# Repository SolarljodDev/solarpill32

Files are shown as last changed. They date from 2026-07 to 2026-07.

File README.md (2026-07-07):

# SolarPill32

A small, STM32-pin-compatible development/breakout board built around the
**CH32V303CBT6** (WCH, RISC-V32, LQFP-48). Footprint and pinout follow the
classic "blue pill / black pill" layout used by STM32F103C8T6 boards, so it
can be used as a drop-in RISC-V alternative in existing STM32 blue/black pill
projects and carriers.

## Board

- MCU: CH32V303CBT6, LQFP-48, 7x7 mm, 0.5 mm pitch (custom footprint
  `LQFP-48_7x7mm_P0.5mm.kicad_mod` included, as it's not in stock KiCad
  libraries).
- 4-layer PCB: top/bottom signal layers plus dedicated GND and 3V3 inner
  planes.
- Designed in KiCad 9.

## Repository contents

| Path | Description |
|---|---|
| `ch32_v303cb.kicad_pro/.kicad_sch/.kicad_pcb` | Main board project (schematic, layout) |
| `filter.kicad_sch` | Hierarchical sheet: power supply filtering |
| `LQFP-48_7x7mm_P0.5mm.kicad_mod` | Custom footprint for the CH32V303CBT6 |
| `SW_conv/` | Secondary small PCB project: switching converter module |
| `gerber/` | Exported Gerber + drill files for fabrication |

Files that KiCad regenerates automatically (autosave backups, `.lck` lock
files, `fp-info-cache`, local `.kicad_prl` view-state files, editor history)
are intentionally excluded — see `.gitignore`.

## License

Hardware design files (schematics, PCB layout, footprints, Gerbers) in this
repository are licensed under the
[CERN Open Hardware Licence Version 2 - Strongly Reciprocal (CERN-OHL-S-2.0)](LICENSE).

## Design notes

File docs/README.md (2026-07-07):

# SolarPill32 pinout configurator

Self-contained interactive HTML page: IDC pin layouts for all 5 headers, with
checkboxes to toggle alternate peripheral functions per pin group. Conflicting
selections (two peripherals wanting the same physical pin) are highlighted
live on the ribbon diagram and pin table.

No build step, no dependencies — `index.html` is the whole page (fonts are
inlined as base64). Open it directly in a browser, or serve this folder
(e.g. via GitHub Pages) as-is.

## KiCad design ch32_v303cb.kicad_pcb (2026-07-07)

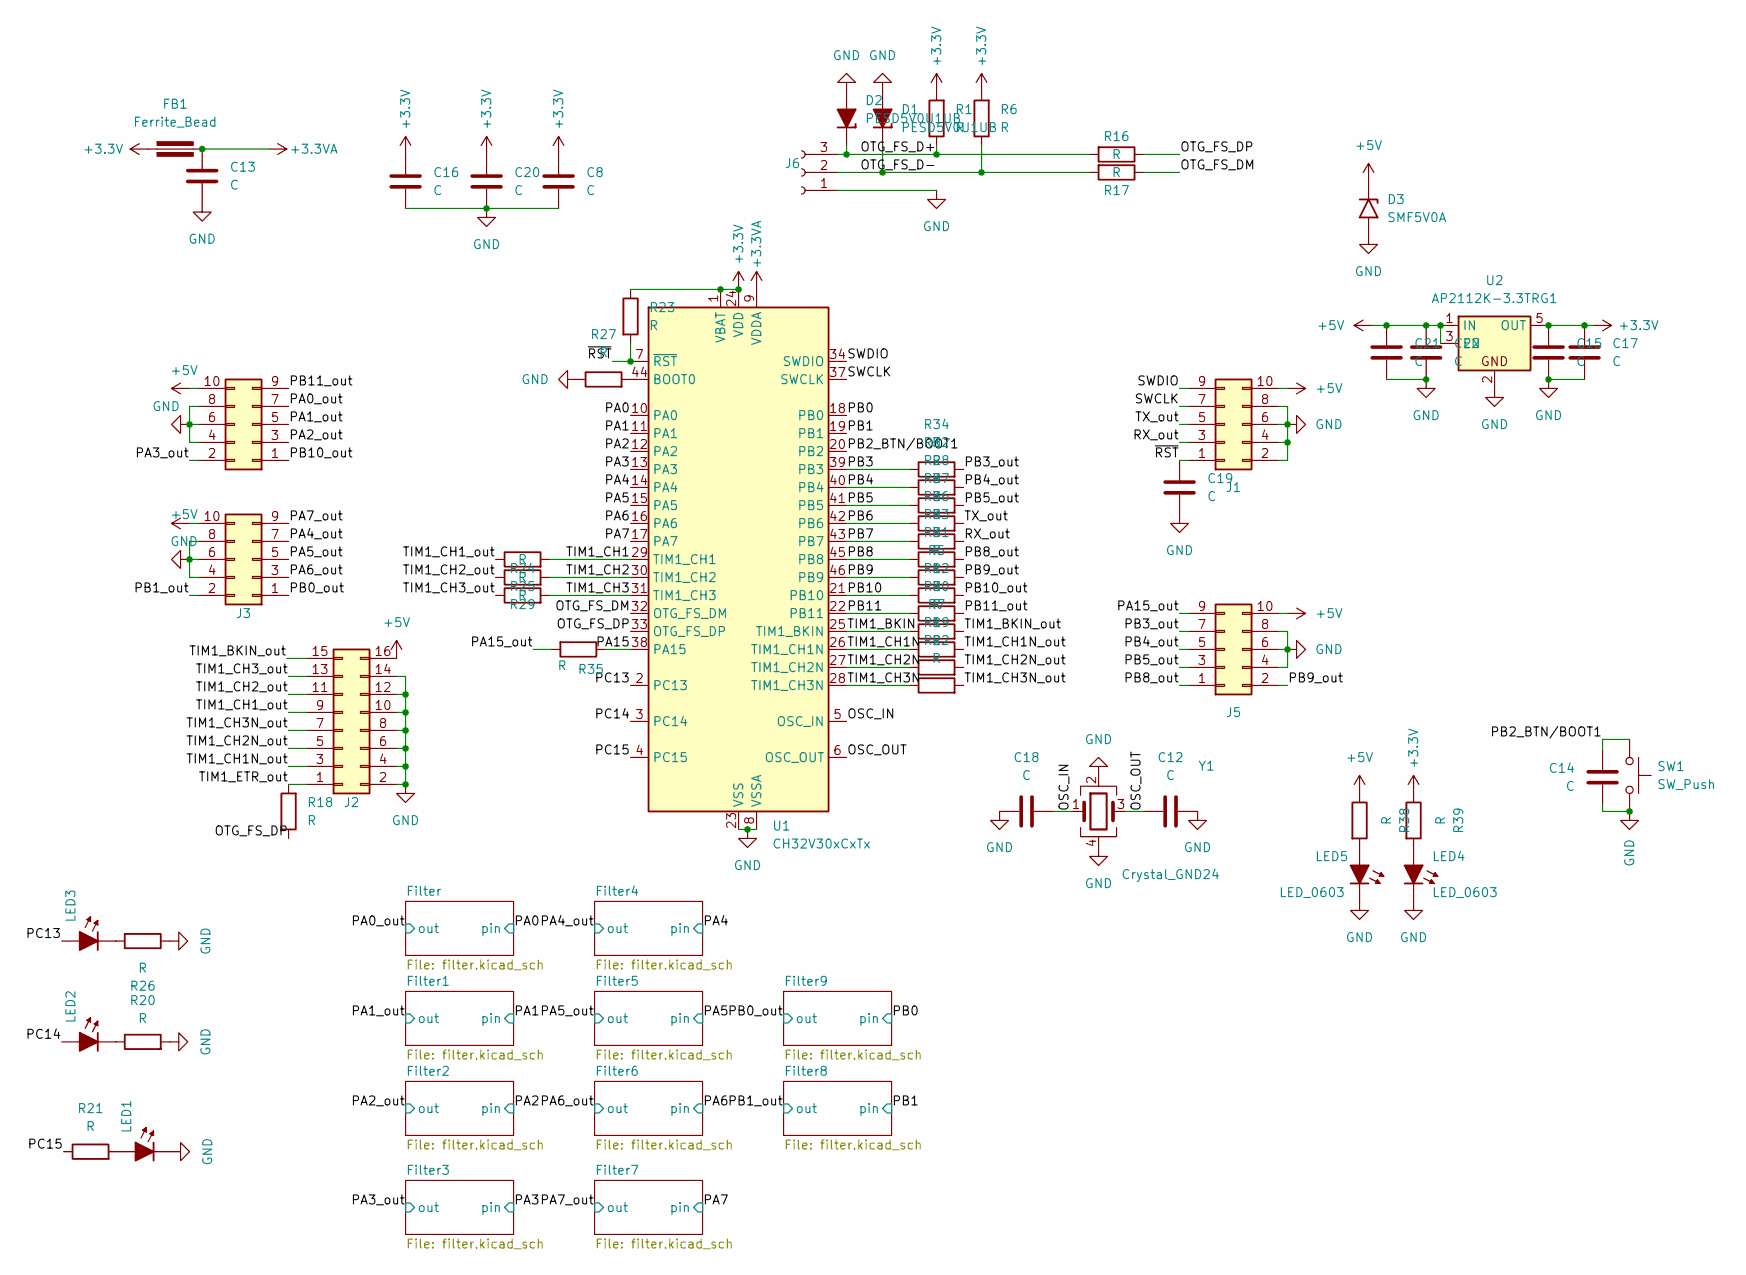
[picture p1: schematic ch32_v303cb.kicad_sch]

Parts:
C8, C12, C13, C14, C15, C16, C17, C18, C19, C20, C21, C22: C; C_0603
D1, D2: PESD5V0U1UB; D_SOD-523
D3: SMF5V0A; D_SMF
FB1: Ferrite_Bead; Ferrite_0603
J1, J3, J4, J5: Conn_02x05_Odd_Even; IDC-Header_2x5_P2.54mm_Horizontal_EDGE
J2: Conn_02x08_Odd_Even; IDC-Header_2x8_P2.54mm_Horizontal_EDGE
J6: Conn_01x02_Socket; PinSocket_1x03_P2.00mm_Vertical
LED1, LED2, LED3, LED4, LED5: LED_0603
R1, R5, R6, R7, R12, R16, R17, R18, R19, R20, R21, R22, R23, R24, R25, R26, R27, R28, R29, R30, R31, R32, R33, R34, R35, R36, R37, R38, R39: R; R_0603
SW1: SW_Push; SW_Push_1P1T_XKB_TS-1187A
U1: CH32V30xCxTx; LQFP-48_7x7mm_P0.5mm
U2: AP2112K-3.3TRG1; SOT-23-5
Y1: Crystal_GND24; Q3225

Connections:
+3.3VA: C13.1, FB1.2, U1.9 (VDDA)
+5V: C21.1, C22.1, D3.1 (A1), J1.10, J2.16, J3.10, J4.10, J5.10, R38.1, U2.1 (IN), U2.3 (EN)
/OSC_IN: C18.2, U1.5 (OSC_IN), Y1.1
/OSC_OUT: C12.1, U1.6 (OSC_OUT), Y1.3
/OTG_FS_D+: D2.1 (K), J6.3, R1.1, R16.2
/OTG_FS_D-: D1.1 (K), J6.2, R6.1, R17.2
/OTG_FS_DM: R17.1, U1.32 (OTG_FS_DM)
/OTG_FS_DP: R16.1, R18.1, U1.33 (OTG_FS_DP)
/PA0: U1.10 (PA0); also elsewhere on the board
/PA0_out: J4.7; also elsewhere on the board
/PA1: U1.11 (PA1); also elsewhere on the board
/PA1_out: J4.5; also elsewhere on the board
/PA2: U1.12 (PA2); also elsewhere on the board
/PA2_out: J4.3; also elsewhere on the board
/PA3: U1.13 (PA3); also elsewhere on the board
/PA3_out: J4.2; also elsewhere on the board
/PA4: U1.14 (PA4); also elsewhere on the board
/PA4_out: J3.7; also elsewhere on the board
/PA5: U1.15 (PA5); also elsewhere on the board
/PA5_out: J3.5; also elsewhere on the board
/PA6: U1.16 (PA6); also elsewhere on the board
/PA6_out: J3.3; also elsewhere on the board
/PA7: U1.17 (PA7); also elsewhere on the board
/PA7_out: J3.9; also elsewhere on the board
/PA15: R35.1, U1.38 (PA15)
/PA15_out: J5.9, R35.2
/PB0_out: J3.1; also elsewhere on the board
/PB1: U1.19 (PB1); also elsewhere on the board
/PB1_out: J3.2; also elsewhere on the board
/PB2_BTN/BOOT1: C14.1, SW1.1, U1.20 (PB2)
/PB3: R34.1, U1.39 (PB3)
/PB3_out: J5.7, R34.2
/PB4: R32.1, U1.40 (PB4)
/PB4_out: J5.5, R32.2
/PB5: R28.1, U1.41 (PB5)
/PB5_out: J5.3, R28.2
/PB6: R37.1, U1.42 (PB6)
/PB7: R36.1, U1.43 (PB7)
/PB8: R33.1, U1.45 (PB8)
/PB8_out: J5.1, R33.2
/PB9: R31.1, U1.46 (PB9)
/PB9_out: J5.2, R31.2
/PB10: R5.1, U1.21 (PB10)
/PB10_out: J4.1, R5.2
/PB11: R12.1, U1.22 (PB11)
/PB11_out: J4.9, R12.2
/PC13: LED3.2 (A), U1.2 (PC13)
/PC14: LED2.2 (A), U1.3 (PC14)
/PC15: R21.1, U1.4 (PC15)
/RX_out: J1.3, R36.2
/SWCLK: J1.7, U1.37 (SWCLK)
/SWDIO: J1.9, U1.34 (SWDIO)
/TIM1_BKIN: R30.1, U1.25 (TIM1_BKIN)
/TIM1_BKIN_out: J2.15, R30.2
/TIM1_CH1: R24.2, U1.29 (TIM1_CH1)
/TIM1_CH1N: R7.1, U1.26 (TIM1_CH1N)
/TIM1_CH1N_out: J2.3, R7.2
/TIM1_CH1_out: J2.9, R24.1
/TIM1_CH2: R25.2, U1.30 (TIM1_CH2)
/TIM1_CH2N: R19.1, U1.27 (TIM1_CH2N)
/TIM1_CH2N_out: J2.5, R19.2
/TIM1_CH2_out: J2.11, R25.1
/TIM1_CH3: R29.2, U1.31 (TIM1_CH3)
/TIM1_CH3N: R22.1, U1.28 (TIM1_CH3N)
/TIM1_CH3N_out: J2.7, R22.2
/TIM1_CH3_out: J2.13, R29.1
/TIM1_ETR_out: J2.1, R18.2
/TX_out: J1.5, R37.2
/~RST: C19.1, J1.1, R23.2, U1.7 (~RST)
GND: C8.2, C12.2, C13.2, C14.2, C15.2, C16.2, C17.2, C18.1, C19.2, C20.2, C21.2, C22.2, D1.2 (A), D2.2 (A), D3.2 (A2), J1.2, J1.4, J1.6, J1.8, J2.2, J2.4, J2.6, J2.8, J2.10, J2.12, J2.14, J3.4, J3.6, J3.8, J4.4, J4.6, J4.8, J5.4, J5.6, J5.8, J6.1, LED1.1 (K), LED4.1 (K), LED5.1 (K), R20.2, R26.1, R27.1, SW1.2, U1.8 (VSSA), U1.23 (VSS), U1.35 (VSS), U1.47 (VSS), U2.2, Y1.2, Y1.4; also elsewhere on the board
unnamed: LED5.2 (A), R38.2
unnamed: LED4.2 (A), R39.2
unnamed: LED3.1 (K), R26.2
unnamed: LED2.1 (K), R20.1
unnamed: LED1.2 (A), R21.2
unnamed: R27.2, U1.44 (BOOT0)

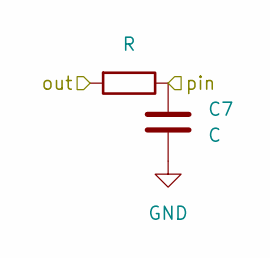
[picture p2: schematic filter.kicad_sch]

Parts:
C7: C; C_0603
R23: R; R_0603

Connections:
/~RST: R23.2; also elsewhere on the board
GND: C7.2; also elsewhere on the board

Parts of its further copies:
C1, C2, C3, C4, C5, C6, C9, C10, C11: C; C_0603
R2, R3, R4, R8, R9, R10, R11, R13, R14, R15: R; R_0603

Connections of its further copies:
/PA0: C4.1, R8.1; also elsewhere on the board
/PA0_out: R8.2; also elsewhere on the board
/PA1: C5.1, R9.1; also elsewhere on the board
/PA1_out: R9.2; also elsewhere on the board
/PA2: C1.1, R2.1; also elsewhere on the board
/PA2_out: R2.2; also elsewhere on the board
/PA3: C3.1, R13.1; also elsewhere on the board
/PA3_out: R13.2; also elsewhere on the board
/PA4: C2.1, R3.1; also elsewhere on the board
/PA4_out: R3.2; also elsewhere on the board
/PA5: C6.1, R10.1; also elsewhere on the board
/PA5_out: R10.2; also elsewhere on the board
/PA6: C10.1, R4.1; also elsewhere on the board
/PA6_out: R4.2; also elsewhere on the board
/PA7: C9.1, R15.1; also elsewhere on the board
/PA7_out: R15.2; also elsewhere on the board
/PB0_out: R11.2; also elsewhere on the board
/PB1: C11.1, R14.1; also elsewhere on the board
/PB1_out: R14.2; also elsewhere on the board
GND: C1.2, C2.2, C3.2, C4.2, C5.2, C6.2, C9.2, C10.2, C11.2; also elsewhere on the board

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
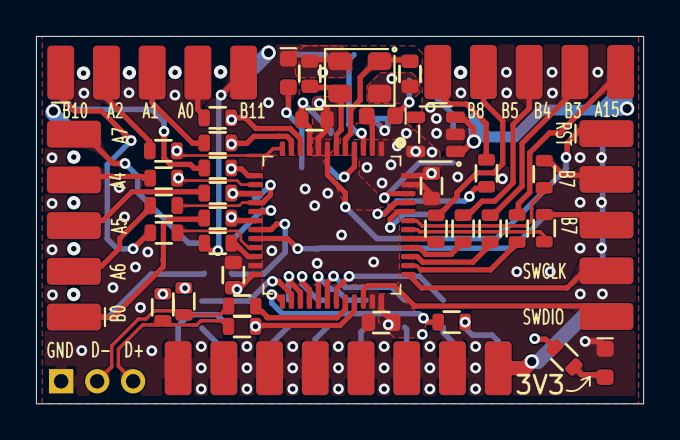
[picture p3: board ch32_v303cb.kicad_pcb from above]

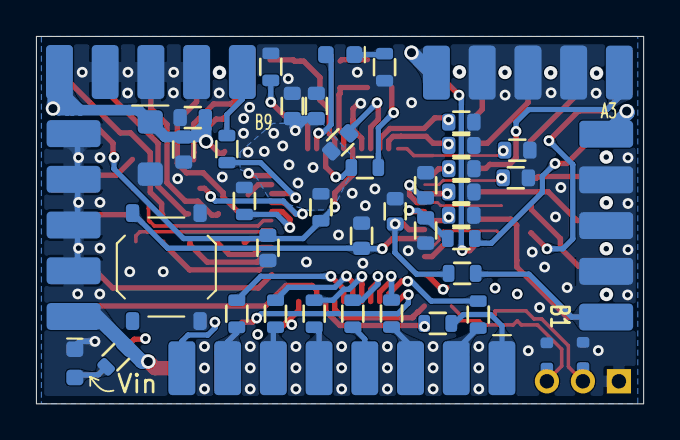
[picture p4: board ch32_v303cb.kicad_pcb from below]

Board: 4 copper layers, 33.7 x 20.4 mm, 80 parts (40 on the bottom side), 78 nets.

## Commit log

2026-07-07 Initial commit: SolarPill32 CH32V303CBT6 dev board
    STM32-pin-compatible (blue/black pill layout) breakout board for the
    CH32V303CBT6, plus a secondary switching converter sub-board. Includes
    KiCad schematics/layout, custom LQFP-48 footprint, and Gerber exports.
    [SW_conv.kicad_pcb, SW_conv.kicad_sch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]
2026-07-07 Renumber components by PCB position; add interactive pinout configurator
    Reference designators for all components (connectors, R, C, LED, including
    the 10 reused filter-sheet instances) now follow physical placement on the
    board instead of arbitrary KiCad placement order. Connectors specifically
    go clockwise starting from the programmer header (J1), with the USB header
    last (J6). Verified electrically identical: ERC/DRC violation counts match
    before/after, and the exported netlist has the exact same 79 nets once old
    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
    [ch32_v303cb.kicad_pcb, ch32_v303cb.kicad_sch, filter.kicad_sch]
2026-07-07 Add ADC1 and MCO options to the pinout configurator
    Missed these on the first pass: ADC1_IN0-3 are broken out on J4 (PA0-PA3)
    and ADC1_IN4-9 on J3 (PA4-PA7, PB0-PB1), plus MCO on J2's PA8 pin. Source:
    Пины.xlsx alternate-function columns for these pads.
2026-07-07 Add DAC1/DAC2 and all 4 op-amp (OPA1-4) options to the pinout configurator
    Found and fixed a bug in the xlsx parser I used to cross-check Пины.xlsx:
    self-closing <c/> cells were being swallowed by a greedy regex branch,
    silently dropping values in several columns. Re-parsed cleanly and picked
    up DAC1_OUT/DAC2_OUT (PA4/PA5, on J3) and the full OPA1-4 input/output
    pin map (spread across J2-J4), plus a TIM1 partial-remap-1 alternative
    (complementary channels move from J2 to J3) that the corrected data
    revealed.
2026-07-07 Remove OPA (op-amp) options from pinout configurator
    Not used and the pin assignments were too fragmented across connectors
    to be a useful checkbox grouping.
2026-10-19 Fix incorrect pins direction and socket shape.
